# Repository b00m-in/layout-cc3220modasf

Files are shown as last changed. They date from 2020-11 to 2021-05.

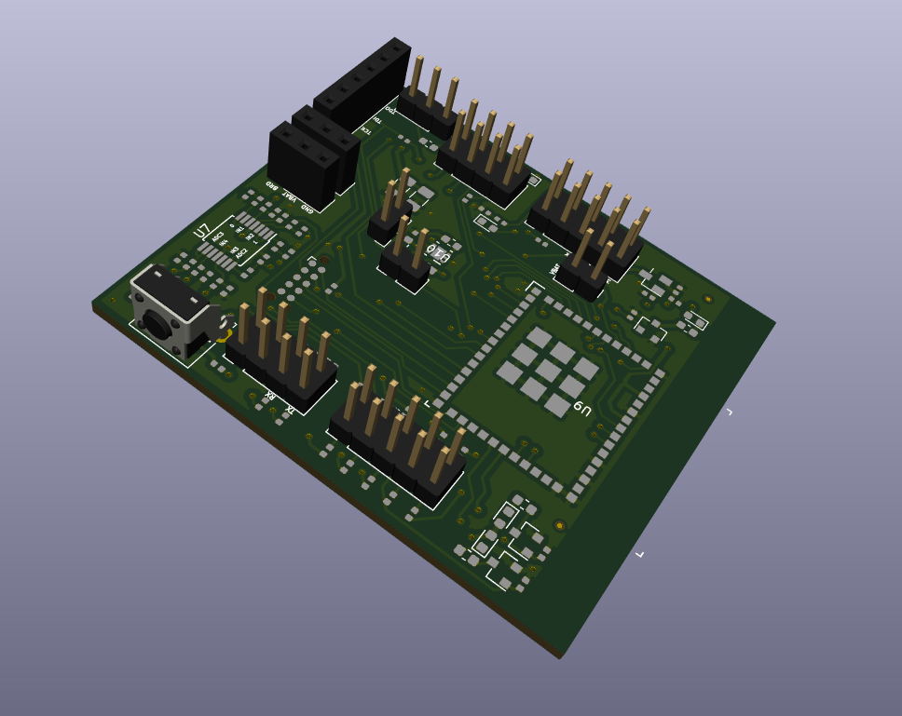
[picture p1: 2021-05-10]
screenshots/b00m_cc3220modas.png

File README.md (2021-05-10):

## [Contents](#contents)

Original CC3220MODASF footprint downloaded from Ultralibrarian.

see ~/dev/kicad/cc3220s/wifi_module/ul_CC3220MODASF12MONR/ (pls ignore - this is a local path) for original CC3220MODASF footprint. Some border lines and through holes in the middle thermal ground pads had to be removed and replaced with vias on the board. 

P.Cu is in fact a ground plane and G.Cu is a power plane

The order of the interface jumpers has changed between CC3220S-LAUNCHXL and LAUNCH-CC3220MODASF. On the former VCC_BRD and VBATT_CC could be jumped as they were next to one another. 

Also J9 came jumped on the former so U7 (op-amp in adc circuit) was powered by VCC_BRD but it's not jumped by default on the latter - didn't catch that as the adc functionality hasn't been yet tested on the latter.  

TMP006AIYZFR is obsolete so was replaced by TMP116NAIDRVR 

## [Layout](#layout)

The following GPIO ports were left unconnected due to space constraints on board:
```
P05_GPIO_14
P06_GPIO_15
P07_GPIO_16
P08_GPIO_17
P18_GPIO_28
P45_GPIO_31 / DCDC_ANA2_SW_P - not connected on dev board either
DCDC_ANA2_SW_N (P46) 
```

CC3220S/F <-> CC3220MODAS
```
Pin55 GPIO1 UART0_TX <-> Pin46
Pin57 GPIO2 UART0_RX <-> Pin47

Pin07 GPIO16 UART1_TX <-> Pin07
Pin08 GPIO17 UART1_RX <-> Pin08
```
~/ti/ccsv8/simplelink_cc32xx_sdk_3_10_00_04/source/ti/boards/CC3220S_LAUNCHXL/CC3220S_LAUNCHXL.c
.rxPin = UARTCC32XX_PIN_08_UART1_RX --> .rxPin = UARTCC32XX_PIN_45_UART1_RX

### [References](#references)
+ [](https://)
+ [](https://) 
+ [](https://)

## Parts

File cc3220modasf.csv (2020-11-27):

Source: | /home/sridhar/dev/kicad/cc3220s/cc3220modasf/cc3220modasf.sch
Date: | Sat 07 Nov 2020 18:14:13 GMT
Tool: | Eeschema 5.1.5-52549c5~84~ubuntu18.04.1
Generator: | /usr/share/kicad/plugins/bom_csv_grouped_by_value.py
Component Count: | 86
Individual Components:
Item | Qty | Reference(s) | Value | LibPart | Footprint | Datasheet | MFG Name | MFG Part Num
 |  | C26 | 0.01uF | Device:C_Small | Capacitor_SMD:C_0402_1005Metric | passive/capacitor/GRM155R61A103KA01-01.pdf | Murata | GRM155R61A103KA01D
 |  | C27 | 0.01uF | Device:C_Small | Capacitor_SMD:C_0402_1005Metric | passive/capacitor/C1005X7R1C103K050BA.pdf | TDK | C1005X7R1C103K
 |  | C28 | 0.01uF | Device:C_Small | Capacitor_SMD:C_0402_1005Metric | passive/capacitor/C1005X7R1C103K050BA.pdf | TDK | C1005X7R1C103K
 |  | C29 | 0.01uF | Device:C_Small | Capacitor_SMD:C_0402_1005Metric | passive/capacitor/C1005X7R1C103K050BA.pdf | TDK | C1005X7R1C103K
 |  | C30 | 0.01uF | Device:C_Small | Capacitor_SMD:C_0402_1005Metric | passive/capacitor/C1005X7R1C103K050BA.pdf | TDK | C1005X7R1C103K
 |  | C33 | 0.1uF | Device:C_Small | Capacitor_SMD:C_0402_1005Metric | passive/capacitor/partnumbering_e_01.pdf | Murata | GRM155R61A104KA01D
 |  | C34 | 0.1uF | Device:C_Small | Capacitor_SMD:C_0402_1005Metric | passive/capacitor/partnumbering_e_01.pdf | Murata | GRM155R61A104KA01D
 |  | C35 | 0.1uF | Device:C_Small | Capacitor_SMD:C_0402_1005Metric | passive/capacitor/partnumbering_e_01.pdf | Murata | GRM155R61A104KA01D
 |  | C41 | 100uF | Device:C_Small | Capacitor_SMD:C_1206_3216Metric | passive/capacitor/partnumbering_e_01.pdf | Murata | GRM31CR60J107ME39L
 |  | C42 | 100uF | Device:C_Small | Capacitor_SMD:C_1206_3216Metric | passive/capacitor/partnumbering_e_01.pdf | Murata | GRM31CR60J107ME39L
 |  | D4 | D_Schottky | Device:D_Schottky | Diode_SMD:D_0603_1608Metric | passive/diode/cd0603-b.pdf | Bourns | CD0603-B0240R/B00340
 |  | D5 | D_Schottky | Device:D_Schottky | Diode_SMD:D_0603_1608Metric | passive/diode/cd0603-b.pdf | Bourns | CD0603-B0240R/B00340
 |  | D8 | GREEN LED | Device:LED | LED_SMD:LED_0603_1608Metric | passive/led/SML-LX0603GW-TR.pdf | Lumex | SML-LX0603GW-TR
 |  | D9 | YELLOW LED | Device:LED | LED_SMD:LED_0603_1608Metric | passive/led/1911348.pdf | Wurth Elektronik eiSos | 150060YS75000
 |  | D10 | RED LED | Device:LED | LED_SMD:LED_0603_1608Metric | passive/led/SML-31_Series.pdf | Rohm | SML-311UTT86
 |  | FID1 | Fiducial | Mechanical:Fiducial | Fiducial:Fiducial_0.5mm_Mask1mm | ~
 |  | FID2 | Fiducial | Mechanical:Fiducial | Fiducial:Fiducial_0.5mm_Mask1mm | ~
 |  | FID3 | Fiducial | Mechanical:Fiducial | Fiducial:Fiducial_0.5mm_Mask1mm | ~
 |  | J1 | Conn_02x05_Odd_Even | Connector_Generic:Conn_02x05_Odd_Even | Connector_PinHeader_2.54mm:PinHeader_2x05_P2.54mm_Vertical | ~ | Samtec Inc | TSW-105-15-G-D
 |  | J2 | Conn_02x05_Odd_Even | Connector_Generic:Conn_02x05_Odd_Even | Connector_PinHeader_2.54mm:PinHeader_2x05_P2.54mm_Vertical | ~ | Samtec Inc | TSW-105-15-G-D
 |  | J3 | Conn_01x06 | Connector_Generic:Conn_01x06 | Connector_PinSocket_2.54mm:PinSocket_1x06_P2.54mm_Vertical | ~ | Wurth | '61301021121
 |  | J5 | Conn_01x03 | Connector_Generic:Conn_01x03 | Connector_PinSocket_2.54mm:PinSocket_1x03_P2.54mm_Vertical | ~
 |  | J6 | Conn_01x03 | Connector_Generic:Conn_01x03 | Connector_PinSocket_2.54mm:PinSocket_1x03_P2.54mm_Vertical | ~
 |  | J10 | Conn_01x02 | Connector_Generic:Conn_01x02 | Connector_PinHeader_2.54mm:PinHeader_1x02_P2.54mm_Vertical | ~ | Wurth Elektronik | '61300211121
 |  | J11 | Conn_02x04_Odd_Even | Connector_Generic:Conn_02x04_Odd_Even | Connector_PinHeader_2.54mm:PinHeader_2x04_P2.54mm_Vertical | ~
 |  | J13 | Conn_02x05_Counter_Clockwise | Connector_Generic:Conn_02x05_Counter_Clockwise | pwrcon:Tag-Connect_TC2050-IDC-NL_2x05_P1.27mm_Vertical_CC_SMD | ~
 |  | J14 | Conn_01x02 | Connector_Generic:Conn_01x02 | Connector_PinHeader_2.54mm:PinHeader_1x02_P2.54mm_Vertical | ~ | Wurth Elektronik | '61300211121
 |  | J15 | Conn_01x02 | Connector_Generic:Conn_01x02 | Connector_PinHeader_2.54mm:PinHeader_1x02_P2.54mm_Vertical | ~ | Wurth Elektronik | '61300211121
 |  | J22 | Conn_02x04_Odd_Even | Connector_Generic:Conn_02x04_Odd_Even | Connector_PinHeader_2.54mm:PinHeader_2x04_P2.54mm_Vertical | ~
 |  | J26 | Conn_01x03 | Connector_Generic:Conn_01x03 | Connector_PinHeader_2.54mm:PinHeader_1x03_P2.54mm_Vertical | ~ | Wurth Elektronik | '61300311121
 |  | Q4 | BSS138 | Transistor_FET:BSN20 | Package_TO_SOT_SMD:SOT-23 | active/BSS138-D.PDF | Fairchild | BSS138
 |  | Q5 | FDN358P | Transistor_FET:TP0610T | Package_TO_SOT_SMD:SuperSOT-3 | active/FDN358P-1305850.pdf | Diodes Inc | FDN358P
 |  | Q6 | BSS138 | Transistor_FET:BSN20 | Package_TO_SOT_SMD:SOT-23 | active/BSS138-D.PDF | Fairchild | BSS138
 |  | Q7 | BSS138 | Transistor_FET:BSN20 | Package_TO_SOT_SMD:SOT-23 | active/BSS138-D.PDF | Fairchild | BSS138
 |  | R44 | 0 | Device:R_Small | Resistor_SMD:R_0402_1005Metric | ~ | Panasonic | ERJ-2GE0R00X
 |  | R49 | 0 | Device:R_Small | Resistor_SMD:R_0402_1005Metric | ~ | Panasonic | ERJ-2GE0R00X
 |  | R50 | 0 | Device:R_Small | Resistor_SMD:R_0402_1005Metric | ~ | Panasonic | ERJ-2GE0R00X
 |  | R53 | 0 | Device:R_Small | Resistor_SMD:R_0402_1005Metric | ~ | Panasonic | ERJ-2GE0R00X
 |  | R54 | 0 | Device:R_Small | Resistor_SMD:R_0402_1005Metric | ~ | Panasonic | ERJ-2GE0R00X
 |  | R57 | 0 | Device:R_Small | Resistor_SMD:R_0402_1005Metric | ~ | Panasonic | ERJ-2GE0R00X
 |  | R58 | 0 | Device:R_Small | Resistor_SMD:R_0402_1005Metric | ~ | Panasonic | ERJ-2GE0R00X
 |  | R60 | 0 | Device:R_Small | Resistor_SMD:R_0402_1005Metric | ~ | Panasonic | ERJ-2GE0R00X
 |  | R62 | 0 | Device:R_Small | Resistor_SMD:R_0402_1005Metric | ~ | Panasonic | ERJ-2GE0R00X
 |  | R63 | 0 | Device:R_Small | Resistor_SMD:R_0402_1005Metric | ~ | Panasonic | ERJ-2GE0R00X
 |  | R64 | 0 | Device:R_Small | Resistor_SMD:R_0402_1005Metric | ~ | Panasonic | ERJ-2GE0R00X
 |  | R65 | 0 | Device:R_Small | Resistor_SMD:R_0402_1005Metric | ~ | Panasonic | ERJ-2GE0R00X
 |  | R66 | 0 | Device:R_Small | Resistor_SMD:R_0402_1005Metric | ~ | Panasonic | ERJ-2GE0R00X
 |  | R69 | 0 | Device:R_Small | Resistor_SMD:R_0402_1005Metric | ~ | Panasonic | ERJ-2GE0R00X
 |  | R71 | 0 | Device:R_Small | Resistor_SMD:R_0402_1005Metric | ~ | Panasonic | ERJ-2GE0R00X
 |  | R72 | 0 | Device:R_Small | Resistor_SMD:R_0402_1005Metric | ~ | Panasonic | ERJ-2GE0R00X
 |  | R73 | 0 | Device:R_Small | Resistor_SMD:R_0402_1005Metric | ~ | Panasonic | ERJ-2GE0R00X
 |  | R74 | 0 | Device:R_Small | Resistor_SMD:R_0402_1005Metric | ~ | Panasonic | ERJ-2GE0R00X
 |  | R84 | 470R | Device:R_Small | Resistor_SMD:R_0402_1005Metric | passive/resistor/AOA0000C304.pdf | Panasonic | ERJ-2RKF4700X
 |  | R85 | 576K | Device:R_Small | Resistor_SMD:R_0402_1005Metric | passive/resistor/dcrcwe3.pdf | Vishay-Dale | CRCW0402576KFKED
 |  | R86 | 576K | Device:R_Small | Resistor_SMD:R_0402_1005Metric | passive/resistor/dcrcwe3.pdf | Vishay-Dale | CRCW0402576KFKED
 |  | R87 | 470R | Device:R_Small | Resistor_SMD:R_0402_1005Metric | passive/resistor/AOA0000C304.pdf | Panasonic | ERJ-2RKF4700X
 |  | R88 | 422K | Device:R_Small | Resistor_SMD:R_0402_1005Metric | passive/resistor/dcrcwe3.pdf | Vishay-Dale | CRCW0402422KFKED
 |  | R89 | 422K | Device:R_Small | Resistor_SMD:R_0402_1005Metric | passive/resistor/dcrcwe3.pdf | Vishay-Dale | CRCW0402422KFKED
 |  | R92 | 470R | Device:R_Small | Resistor_SMD:R_0402_1005Metric | passive/resistor/AOA0000C304.pdf | Panasonic | ERJ-2RKF4700X
 |  | R93 | 470R | Device:R_Small | Resistor_SMD:R_0402_1005Metric | passive/resistor/AOA0000C304.pdf | Panasonic | ERJ-2RKF4700X
 |  | R94 | 576K | Device:R_Small | Resistor_SMD:R_0402_1005Metric | passive/resistor/dcrcwe3.pdf | Vishay-Dale | CRCW0402576KFKED
 |  | R95 | 576K | Device:R_Small | Resistor_SMD:R_0402_1005Metric | passive/resistor/dcrcwe3.pdf | Vishay-Dale | CRCW0402576KFKED
 |  | R96 | 422K | Device:R_Small | Resistor_SMD:R_0402_1005Metric | passive/resistor/dcrcwe3.pdf | Vishay-Dale | CRCW0402422KFKED
 |  | R97 | 422K | Device:R_Small | Resistor_SMD:R_0402_1005Metric | passive/resistor/dcrcwe3.pdf | Vishay-Dale | CRCW0402422KFKED
 |  | R105 | 0 | Device:R_Small | Resistor_SMD:R_0402_1005Metric | ~ | Panasonic | ERJ-2GE0R00X
 |  | R107 | 270R | Device:R_Small | Resistor_SMD:R_0603_1608Metric | passive/resistor/crcwce3.pdf | Vishay-Dale | CRCW0603270RJNEA
 |  | R108 | 100K | Device:R_Small | Resistor_SMD:R_0402_1005Metric | passive/resistor/dcrcwpe3.pdf | Vishay-Dale | CRCW0402100KDHEDP
 |  | R109 | 2.2K | Device:R_Small | Resistor_SMD:R_0402_1005Metric | passive/resistor/dcrcwe3.pdf | Vishay-Dale | CRCW04022K20JNED
 |  | R113 | 10K | Device:R_Small | Resistor_SMD:R_0402_1005Metric | passive/resistor/dcrcwe3.pdf | Vishay-Dale | CRCW040210K0JNED
 |  | R116 | 4k87 | Device:R_Small | Resistor_SMD:R_0603_1608Metric | passive/resistor/dcrcwe3.pdf | Vishay-Dale | CRCW06034K87FKEA
 |  | R117 | 4k87 | Device:R_Small | Resistor_SMD:R_0603_1608Metric | passive/resistor/dcrcwe3.pdf | Vishay-Dale | CRCW06034K87FKEA
 |  | R118 | 4k87 | Device:R_Small | Resistor_SMD:R_0603_1608Metric | passive/resistor/dcrcwe3.pdf | Vishay-Dale | CRCW06034K87FKEA
 |  | R134 | 100K | Device:R_Small | Resistor_SMD:R_0402_1005Metric | passive/resistor/dcrcwe3.pdf | Vishay-Dale | CRCW0402100KJNED
 |  | R136 | 1K | Device:R_Small | Resistor_SMD:R_0402_1005Metric | passive/resistor/crcwce3.pdf | Vishay-Dale | CRCW04021K00JNEDC
 |  | R139 | 10K | Device:R_Small | Resistor_SMD:R_0402_1005Metric | passive/resistor/crcwce3.pdf | Vishay-Dale | CRCW040210K0JNEDC
 |  | R145 | 270R | Device:R_Small | Resistor_SMD:R_0603_1608Metric | passive/resistor/crcwce3.pdf | Vishay-Dale | CRCW0603270RJNEAC
 |  | R146 | 270R | Device:R_Small | Resistor_SMD:R_0603_1608Metric | passive/resistor/crcwce3.pdf | Vishay-Dale | CRCW0603270RJNEAC
 |  | R147 | 270R | Device:R_Small | Resistor_SMD:R_0603_1608Metric | passive/resistor/crcwce3.pdf | Vishay-Dale | CRCW0603270RJNEAC
 |  | R149 | 100K | Device:R_Small | Resistor_SMD:R_0402_1005Metric | passive/resistor/crcwce3.pdf | Vishay-Dale | CRCW0402100KJNEDC
 |  | R150 | 100K | Device:R_Small | Resistor_SMD:R_0402_1005Metric | passive/resistor/crcwce3.pdf | Vishay-Dale | CRCW0402100KJNEDC
 |  | R151 | 100K | Device:R_Small | Resistor_SMD:R_0402_1005Metric | passive/resistor/crcwce3.pdf | Vishay-Dale | CRCW0402100KJNEDC
 |  | R152 | 0 | Device:R_Small | Resistor_SMD:R_0402_1005Metric | ~ | Panasonic | ERJ-2GE0R00X
 |  | SW2 | SW_DIP_x01 | Switch:SW_DIP_x01 | Button_Switch_THT:SW_Tactile_SPST_Angled_PTS645Vx31-2LFS | ~ | APEM | MJTP1117
 |  | U7 | OPA4340UA | Amplifier_Operational:OPA4340UA | Package_SO:TSSOP-14_4.4x5mm_P0.65mm | active/opa340.pdf | Texas Instruments | OPA4342EA/250
 |  | U9 | CC3220MODASF12MONR | cc3220modasf:CC3220MODASF12MONR | CC3220MODASF12MONR:CC3220MODASF12MONR | ic/cc3220moda.pdf | Texas Instruments | CC3220MODASF12MON
 |  | U10 | TMP116AIDRVR | tmp116:TMP116AIDRVR | TMP116:TMP116AIDRVR | ic/tmp116.pdf | Texas Instruments | TMP116NAIDRVR
Collated Components:
Item | Qty | Reference(s) | Value | LibPart | Footprint | Datasheet | MFG Name | MFG Part Num
1 | 5 | C26, C27, C28, C29, C30 | 0.01uF | Device:C_Small | Capacitor_SMD:C_0402_1005Metric | passive/capacitor/GRM155R61A103KA01-01.pdf | Murata | GRM155R61A103KA01D
2 | 3 | C33, C34, C35 | 0.1uF | Device:C_Small | Capacitor_SMD:C_0402_1005Metric | passive/capacitor/partnumbering_e_01.pdf | Murata | GRM155R61A104KA01D
3 | 2 | C41, C42 | 100uF | Device:C_Small | Capacitor_SMD:C_1206_3216Metric | passive/capacitor/partnumbering_e_01.pdf | Murata | GRM31CR60J107ME39L
4 | 2 | D4, D5 | D_Schottky | Device:D_Schottky | Diode_SMD:D_0603_1608Metric | passive/diode/cd0603-b.pdf | Bourns | CD0603-B0240R/B00340
5 | 1 | D8 | GREEN LED | Device:LED | LED_SMD:LED_0603_1608Metric | passive/led/SML-LX0603GW-TR.pdf | Lumex | SML-LX0603GW-TR
6 | 1 | D9 | YELLOW LED | Device:LED | LED_SMD:LED_0603_1608Metric | passive/led/1911348.pdf | Wurth Elektronik eiSos | 150060YS75000
7 | 1 | D10 | RED LED | Device:LED | LED_SMD:LED_0603_1608Metric | passive/led/SML-31_Series.pdf | Rohm | SML-311UTT86
8 | 3 | FID1, FID2, FID3 | Fiducial | Mechanical:Fiducial | Fiducial:Fiducial_0.5mm_Mask1mm | ~
9 | 2 | J1, J2 | Conn_02x05_Odd_Even | Connector_Generic:Conn_02x05_Odd_Even | Connector_PinHeader_2.54mm:PinHeader_2x05_P2.54mm_Vertical | ~ | Samtec Inc | TSW-105-15-G-D
10 | 1 | J3 | Conn_01x06 | Connector_Generic:Conn_01x06 | Connector_PinSocket_2.54mm:PinSocket_1x06_P2.54mm_Vertical | ~ | Wurth | '61301021121
11 | 2 | J5, J6 | Conn_01x03 | Connector_Generic:Conn_01x03 | Connector_PinSocket_2.54mm:PinSocket_1x03_P2.54mm_Vertical | ~
12 | 3 | J10, J14, J15 | Conn_01x02 | Connector_Generic:Conn_01x02 | Connector_PinHeader_2.54mm:PinHeader_1x02_P2.54mm_Vertical | ~ | Wurth Elektronik | '61300211121
13 | 2 | J11, J22 | Conn_02x04_Odd_Even | Connector_Generic:Conn_02x04_Odd_Even | Connector_PinHeader_2.54mm:PinHeader_2x04_P2.54mm_Vertical | ~
14 | 1 | J13 | Conn_02x05_Counter_Clockwise | Connector_Generic:Conn_02x05_Counter_Clockwise | pwrcon:Tag-Connect_TC2050-IDC-NL_2x05_P1.27mm_Vertical_CC_SMD | ~
15 | 1 | J26 | Conn_01x03 | Connector_Generic:Conn_01x03 | Connector_PinHeader_2.54mm:PinHeader_1x03_P2.54mm_Vertical | ~ | Wurth Elektronik | '61300311121
16 | 3 | Q4, Q6, Q7 | BSS138 | Transistor_FET:BSN20 | Package_TO_SOT_SMD:SOT-23 | active/BSS138-D.PDF | Fairchild | BSS138
17 | 1 | Q5 | FDN358P | Transistor_FET:TP0610T | Package_TO_SOT_SMD:SuperSOT-3 | active/FDN358P-1305850.pdf | Diodes Inc | FDN358P
18 | 20 | R44, R49, R50, R53, R54, R57, R58, R60, R62, R63, R64, R65, R66, R69, R71, R72, R73, R74, R105, R152 | 0 | Device:R_Small | Resistor_SMD:R_0402_1005Metric | ~ | Panasonic | ERJ-2GE0R00X
19 | 4 | R84, R87, R92, R93 | 470R | Device:R_Small | Resistor_SMD:R_0402_1005Metric | passive/resistor/AOA0000C304.pdf | Panasonic | ERJ-2RKF4700X
20 | 4 | R85, R86, R94, R95 | 576K | Device:R_Small | Resistor_SMD:R_0402_1005Metric | passive/resistor/dcrcwe3.pdf | Vishay-Dale | CRCW0402576KFKED
21 | 4 | R88, R89, R96, R97 | 422K | Device:R_Small | Resistor_SMD:R_0402_1005Metric | passive/resistor/dcrcwe3.pdf | Vishay-Dale | CRCW0402422KFKED
22 | 4 | R107, R145, R146, R147 | 270R | Device:R_Small | Resistor_SMD:R_0603_1608Metric | passive/resistor/crcwce3.pdf | Vishay-Dale | CRCW0603270RJNEA
23 | 5 | R108, R134, R149, R150, R151 | 100K | Device:R_Small | Resistor_SMD:R_0402_1005Metric | passive/resistor/dcrcwpe3.pdf | Vishay-Dale | CRCW0402100KDHEDP
24 | 1 | R109 | 2.2K | Device:R_Small | Resistor_SMD:R_0402_1005Metric | passive/resistor/dcrcwe3.pdf | Vishay-Dale | CRCW04022K20JNED
25 | 2 | R113, R139 | 10K | Device:R_Small | Resistor_SMD:R_0402_1005Metric | passive/resistor/dcrcwe3.pdf | Vishay-Dale | CRCW040210K0JNED
26 | 3 | R116, R117, R118 | 4k87 | Device:R_Small | Resistor_SMD:R_0603_1608Metric | passive/resistor/dcrcwe3.pdf | Vishay-Dale | CRCW06034K87FKEA
27 | 1 | R136 | 1K | Device:R_Small | Resistor_SMD:R_0402_1005Metric | passive/resistor/crcwce3.pdf | Vishay-Dale | CRCW04021K00JNEDC
28 | 1 | SW2 | SW_DIP_x01 | Switch:SW_DIP_x01 | Button_Switch_THT:SW_Tactile_SPST_Angled_PTS645Vx31-2LFS | ~ | APEM | MJTP1117
29 | 1 | U7 | OPA4340UA | Amplifier_Operational:OPA4340UA | Package_SO:TSSOP-14_4.4x5mm_P0.65mm | active/opa340.pdf | Texas Instruments | OPA4342EA/250
30 | 1 | U9 | CC3220MODASF12MONR | cc3220modasf:CC3220MODASF12MONR | CC3220MODASF12MONR:CC3220MODASF12MONR | ic/cc3220moda.pdf | Texas Instruments | CC3220MODASF12MON
31 | 1 | U10 | TMP116AIDRVR | tmp116:TMP116AIDRVR | TMP116:TMP116AIDRVR | ic/tmp116.pdf | Texas Instruments | TMP116NAIDRVR

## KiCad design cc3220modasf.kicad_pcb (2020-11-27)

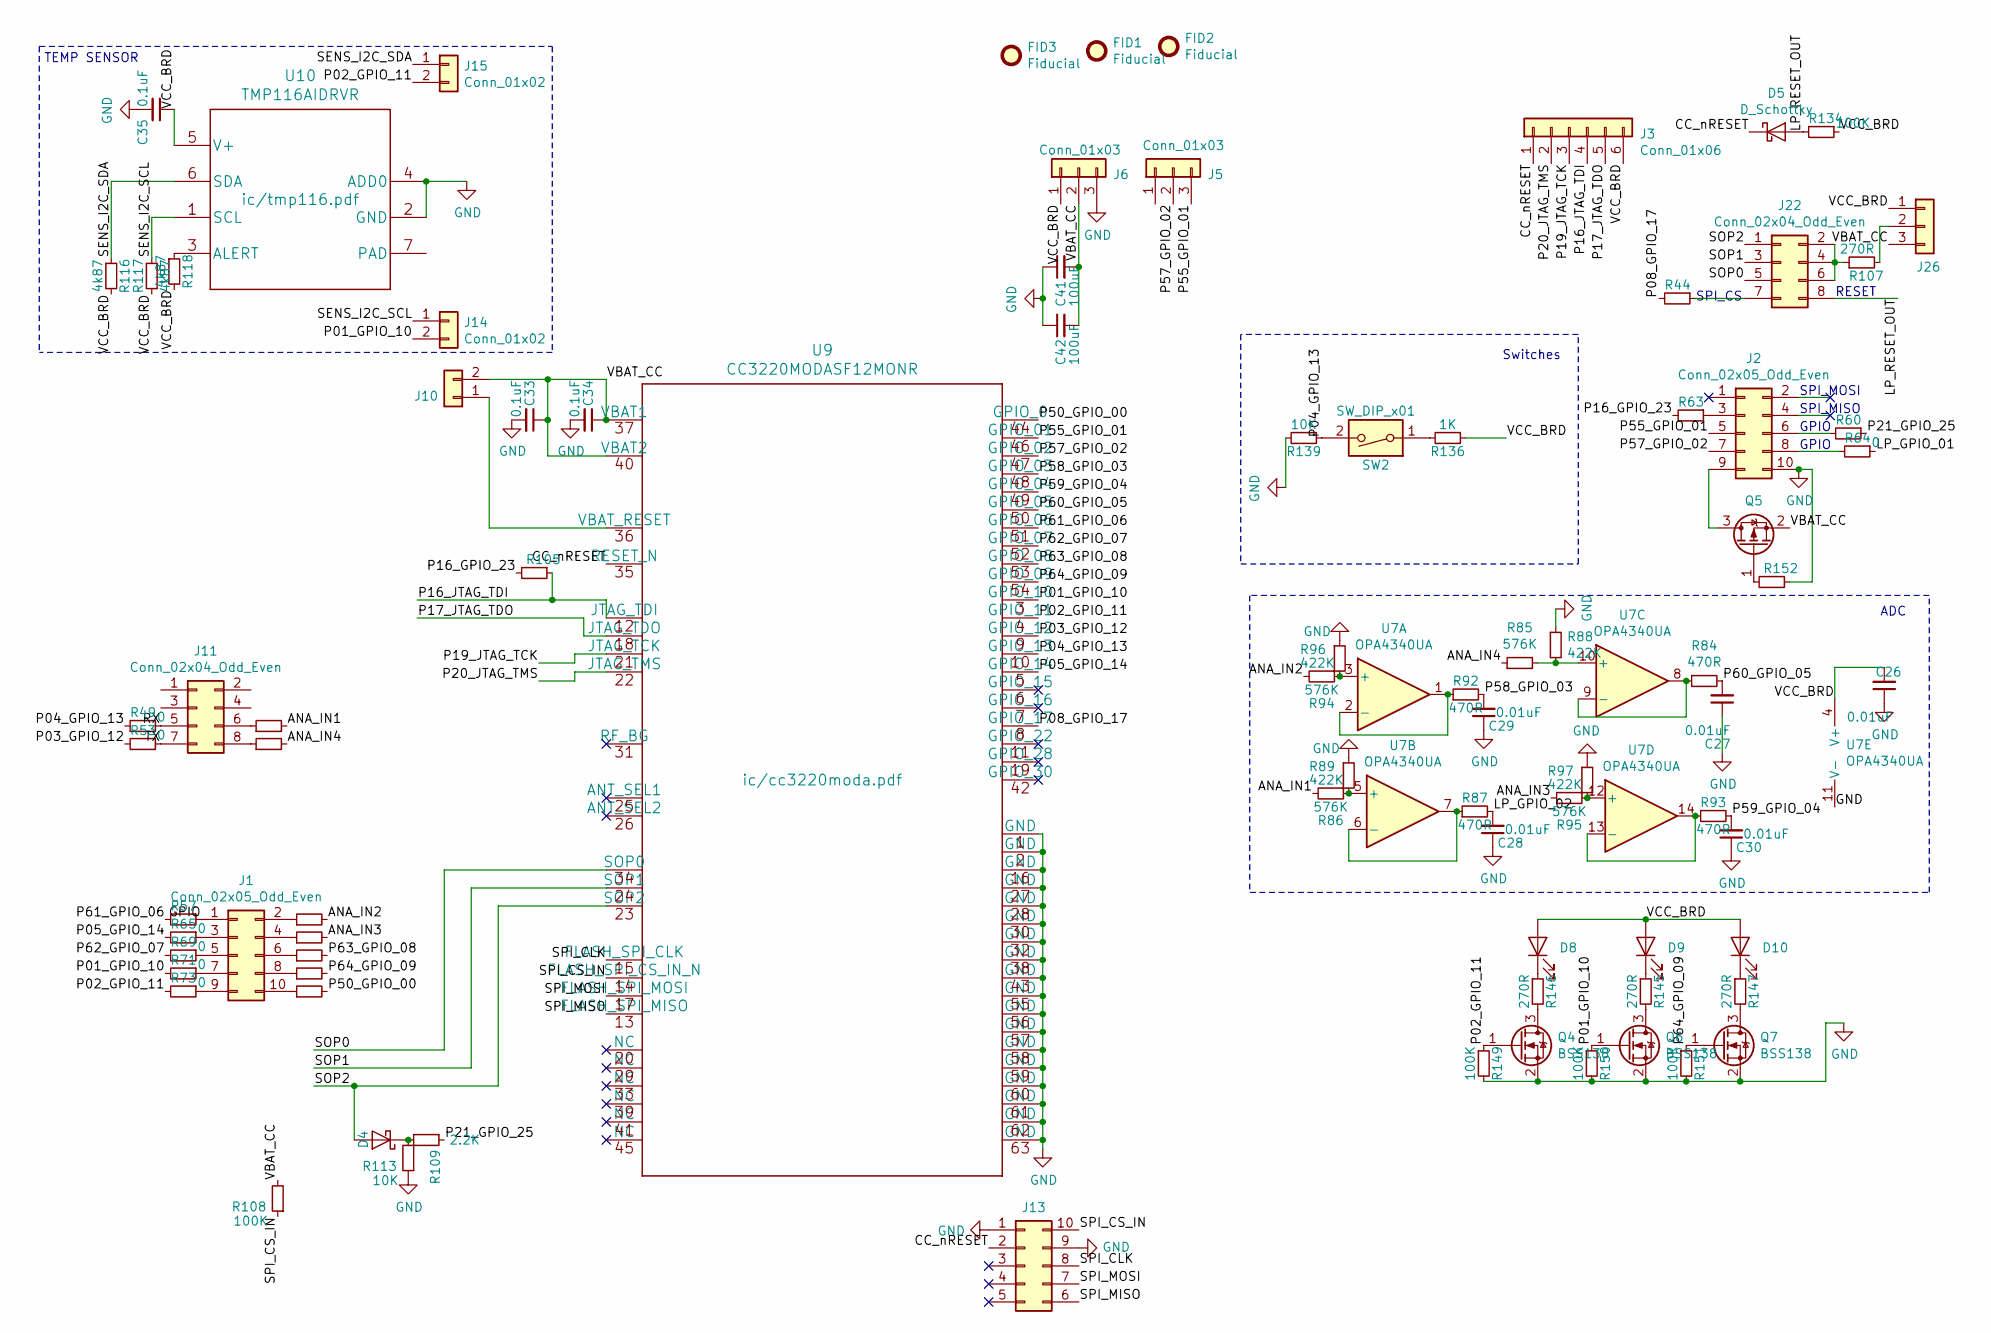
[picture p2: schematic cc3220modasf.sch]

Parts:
C26: 0.01uF; C_0402_1005Metric; MFG Part Num GRM155R61A103KA01D
C27, C28, C29, C30: 0.01uF; C_0402_1005Metric; MFG Part Num C1005X7R1C103K
C33, C34, C35: 0.1uF; C_0402_1005Metric; MFG Part Num GRM155R61A104KA01D
C41, C42: 100uF; C_1206_3216Metric; MFG Part Num GRM31CR60J107ME39L
D4, D5: D_Schottky; D_0603_1608Metric; MFG Part Num CD0603-B0240R/B00340
D8: GREEN LED; LED_0603_1608Metric; MFG Part Num SML-LX0603GW-TR
D9: YELLOW LED; LED_0603_1608Metric; MFG Part Num 150060YS75000
D10: RED LED; LED_0603_1608Metric; MFG Part Num SML-311UTT86
FID1, FID2, FID3: Fiducial; Fiducial_0.5mm_Mask1mm
J1, J2: Conn_02x05_Odd_Even; PinHeader_2x05_P2.54mm_Vertical; MFG Part Num TSW-105-15-G-D
J3: Conn_01x06; PinSocket_1x06_P2.54mm_Vertical; MFG Part Num '61301021121
J5, J6: Conn_01x03; PinSocket_1x03_P2.54mm_Vertical
J10, J14, J15: Conn_01x02; PinHeader_1x02_P2.54mm_Vertical; MFG Part Num '61300211121
J11, J22: Conn_02x04_Odd_Even; PinHeader_2x04_P2.54mm_Vertical
J13: Conn_02x05_Counter_Clockwise; Tag-Connect_TC2050-IDC-NL_2x05_P1.27mm_Vertical_CC_SMD
J26: Conn_01x03; PinHeader_1x03_P2.54mm_Vertical; MFG Part Num '61300311121
Q4, Q6, Q7: BSS138; SOT-23; MFG Part Num BSS138
Q5: FDN358P; SuperSOT-3; MFG Part Num FDN358P
R44, R49, R50, R53, R54, R57, R58, R60, R62, R63, R64, R65, R66, R69, R71, R72, R73, R74, R105, R152: 0; R_0402_1005Metric; MFG Part Num ERJ-2GE0R00X
R84, R87, R92, R93: 470R; R_0402_1005Metric; MFG Part Num ERJ-2RKF4700X
R85, R86, R94, R95: 576K; R_0402_1005Metric; MFG Part Num CRCW0402576KFKED
R88, R89, R96, R97: 422K; R_0402_1005Metric; MFG Part Num CRCW0402422KFKED
R107: 270R; R_0603_1608Metric; MFG Part Num CRCW0603270RJNEA
R108: 100K; R_0402_1005Metric; MFG Part Num CRCW0402100KDHEDP
R109: 2.2K; R_0402_1005Metric; MFG Part Num CRCW04022K20JNED
R113: 10K; R_0402_1005Metric; MFG Part Num CRCW040210K0JNED
R116, R117, R118: 4k87; R_0603_1608Metric; MFG Part Num CRCW06034K87FKEA
R134: 100K; R_0402_1005Metric; MFG Part Num CRCW0402100KJNED
R136: 1K; R_0402_1005Metric; MFG Part Num CRCW04021K00JNEDC
R139: 10K; R_0402_1005Metric; MFG Part Num CRCW040210K0JNEDC
R145, R146, R147: 270R; R_0603_1608Metric; MFG Part Num CRCW0603270RJNEAC
R149, R150, R151: 100K; R_0402_1005Metric; MFG Part Num CRCW0402100KJNEDC
SW2: SW_DIP_x01; SW_Tactile_SPST_Angled_PTS645Vx31-2LFS; MFG Part Num MJTP1117
U7: OPA4340UA; TSSOP-14_4.4x5mm_P0.65mm; MFG Part Num OPA4342EA/250
U9: CC3220MODASF12MONR; MFG Part Num CC3220MODASF12MON
U10: TMP116AIDRVR; MFG Part Num TMP116NAIDRVR

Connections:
/ANA_IN1: R50.2, R86.2
/ANA_IN2: R58.2, R94.2
/ANA_IN3: R62.2, R95.2
/ANA_IN4: R54.2, R85.1
/CC_nRESET: D5.1 (K), J3.1, J13.2, U9.35 (RESET_N)
/GPIO: J1.1, R57.1
/LP_GPIO_02: C28.2, R87.2
/LP_RESET_OUT: D5.2 (A), J22.8, R134.2
/P01_GPIO_10: J14.2, Q6.1 (G), R71.2, R150.1, U9.3 (GPIO_10)
/P02_GPIO_11: J15.2, Q4.1 (G), R73.2, R149.1, U9.4 (GPIO_11)
/P03_GPIO_12: R53.2, U9.9 (GPIO_12)
/P04_GPIO_13: R49.2, R139.1, SW2.2, U9.10 (GPIO_13)
/P05_GPIO_14: R65.2, U9.5 (GPIO_14)
/P08_GPIO_17: R44.2, U9.8 (GPIO_17)
/P16_GPIO_23: R63.2, R105.2
/P16_JTAG_TDI: J3.4, R105.1, U9.12 (JTAG_TDI)
/P17_JTAG_TDO: J3.5, U9.18 (JTAG_TDO)
/P19_JTAG_TCK: J3.3, U9.21 (JTAG_TCK)
/P20_JTAG_TMS: J3.2, U9.22 (JTAG_TMS)
/P21_GPIO_25: R60.1, R109.1
/P50_GPIO_00: R74.2, U9.44 (GPIO_0)
/P55_GPIO_01: J2.5, J5.3, U9.46 (GPIO_01)
/P57_GPIO_02: J2.7, J5.2, U9.47 (GPIO_02)
/P58_GPIO_03: C29.2, R92.2, U9.48 (GPIO_03)
/P59_GPIO_04: C30.2, R93.2, U9.49 (GPIO_04)
/P60_GPIO_05: C27.2, R84.2, U9.50 (GPIO_05)
/P61_GPIO_06: R57.2, U9.51 (GPIO_06)
/P62_GPIO_07: R69.2, U9.52 (GPIO_07)
/P63_GPIO_08: R66.2, U9.53 (GPIO_08)
/P64_GPIO_09: Q7.1 (G), R72.2, R151.1, U9.54 (GPIO_09)
/RX: J11.5, R49.1
/SENS_I2C_SCL: J14.1, R117.2, U10.1 (SCL)
/SENS_I2C_SDA: J15.1, R116.1, U10.6 (SDA)
/SOP0: J22.5, U9.34 (SOP0)
/SOP1: J22.3, U9.24 (SOP1)
/SOP2: D4.2 (A), J22.1, U9.23 (SOP2)
/SPI_CLK: J13.8, U9.15 (FLASH_SPI_CLK)
/SPI_CS_IN: J13.10, R108.1, U9.14 (FLASH_SPI_CS_IN_N)
/SPI_MISO: J13.6, U9.13 (FLASH_SPI_MISO)
/SPI_MOSI: J13.7, U9.17 (FLASH_SPI_MOSI)
/TX: J11.7, R53.1
/VBAT_CC: C33.1, C34.1, C41.2, C42.2, J6.2, J10.2, J26.3, Q5.2 (S), R108.2, U9.37 (VBAT1), U9.40 (VBAT2)
/VCC_BRD: C26.2, C35.1, D8.2 (A), D9.2 (A), D10.2 (A), J3.6, J6.1, J26.1, R116.2, R117.1, R118.2, R134.1, R136.1, U7.4 (V+), U10.5 (V+)
GND: C26.1, C27.1, C28.1, C29.1, C30.1, C33.2, C34.2, C35.2, C41.1, C42.1, J2.10, J6.3, J13.1, J13.9, Q4.2 (S), Q6.2 (S), Q7.2 (S), R88.1, R89.1, R96.1, R97.1, R113.1, R139.2, R149.2, R150.2, R151.2, R152.1, U7.11 (V-), U9.1 (GND), U9.2 (GND), U9.16 (GND), U9.27 (GND), U9.28 (GND), U9.30 (GND), U9.32 (GND), U9.38 (GND), U9.43 (GND), U9.55 (GND), U9.56 (GND), U9.57 (GND), U9.58 (GND), U9.59 (GND), U9.60 (GND), U9.61 (GND), U9.62 (GND), U9.63 (GND), U10.2 (GND), U10.4 (ADD0)
unnamed: D4.1 (K), R109.2, R113.2
unnamed: D8.1 (K), R146.1
unnamed: D9.1 (K), R145.1
unnamed: D10.1 (K), R147.1
unnamed: J1.2, R58.1
unnamed: J1.3, R65.1
unnamed: J1.4, R62.1
unnamed: J1.5, R69.1
unnamed: J1.6, R66.1
unnamed: J1.7, R71.1
unnamed: J1.8, R72.1
unnamed: J1.9, R73.1
unnamed: J1.10, R74.1
unnamed: J2.3, R63.1
unnamed: J2.6, R60.2
unnamed: J2.8, R64.2
unnamed: J2.9, Q5.3 (D)
unnamed: J10.1, U9.36 (VBAT_RESET)
unnamed: J11.6, R50.1
unnamed: J11.8, R54.1
unnamed: J22.2, J22.4, J22.6, R107.1
unnamed: J22.7, R44.1
unnamed: J26.2, R107.2
unnamed: Q4.3 (D), R146.2
unnamed: Q5.1 (G), R152.2
unnamed: Q6.3 (D), R145.2
unnamed: Q7.3 (D), R147.2
unnamed: R84.1, U7.8, U7.9 (-)
unnamed: R85.2, R88.2, U7.10 (+)
unnamed: R86.1, R89.2, U7.5 (+)
unnamed: R87.1, U7.6 (-), U7.7
unnamed: R92.1, U7.1, U7.2 (-)
unnamed: R93.1, U7.13 (-), U7.14
unnamed: R94.1, R96.2, U7.3 (+)
unnamed: R95.1, R97.2, U7.12 (+)
unnamed: R118.1, U10.3 (ALERT)
unnamed: R136.2, SW2.1

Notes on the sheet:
Switches
TEMP SENSOR
ADC
GPIO
SPI_MISO
SPI_MOSI
RESET
SPI_CS

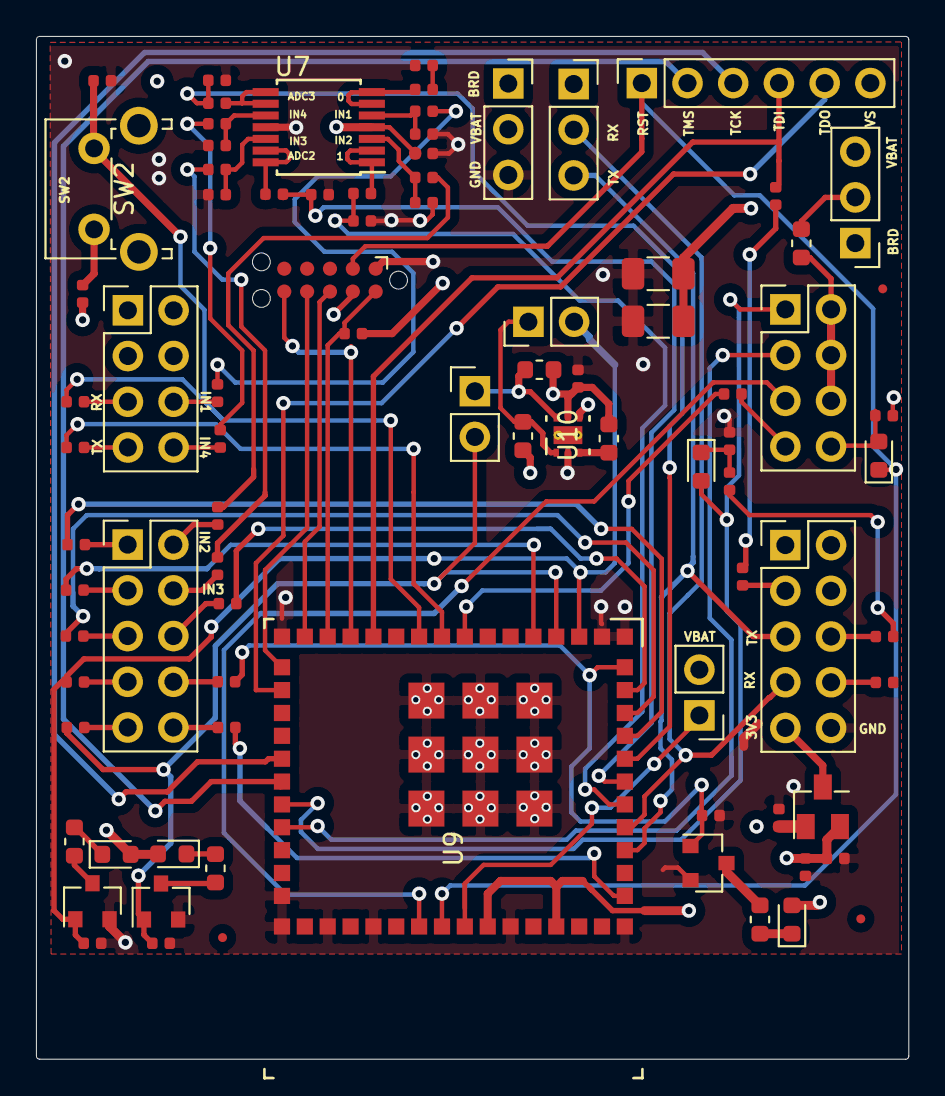
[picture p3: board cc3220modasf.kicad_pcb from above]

Board: 4 copper layers, 48.5 x 56.8 mm, 86 parts (0 on the bottom side), 81 nets.

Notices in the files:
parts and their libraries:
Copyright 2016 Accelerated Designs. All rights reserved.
